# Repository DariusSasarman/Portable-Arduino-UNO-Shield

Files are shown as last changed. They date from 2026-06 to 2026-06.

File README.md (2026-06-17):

# Portable-Arduino-UNO-Shield

## What is it?

A shield that you can use to upgrade older Arduino UNO boards such that your projects don't need extra batteries nor cables. Just the one your phone uses!

## How does it look?



## Physical details:
- **Input:** USB-C (5V, up to 2A for charging)
- **Battery:** 14500 Li-ion Rechargeable (3.7V, 500mAh)
- **Output:** 5V through boost converter ( -0.6V diode voltage drop when running on usb-c !!! )
- **Board Size:** Aprox. 91.5 × 53.4 mm

## Main components
- **Charging IC:** Handles the Li-ion charging (MCP73831-2-OT)
- **Boost Converter:** Steps up 3.7V from the battery to 5V for the Arduino (TPS61200DRC)
- **MOSFET:** Disconects the battery from output when current is fed from USB (PMOS)
- **Reverse Blocking Diode:** Makes sure current doesn't flow backward
- **ESD Diode:** Protects against static discharge on the USB data lines (USBLC6-2SC6)
- **USB to UART converter:** Translates the data lines to actual information (CH340E)

## Installation & usage
1. Pop the 14500 battery into the holder(  Watch the polarity!)
2. Stack the shield onto your Arduino UNO
3. Plug in USB-C to charge (the LED being on means the battery charging)
4. When done charging, unplug and turn on the switch!

## Schematic


## How would this prove useful?

Ever had a project that needed the arduino to be mounted somewhere such that a USB connection couldn't have been possible? I did.

## How did I make it?

I build it by integrating both a standard Li-ion charging circuit (MCP73831 reference design) with a boost converter topology and a USB-serial interface. Added my own custom changes to these, such as the LED and battery switch. It has been a wonderful experiment.

**Key Learnings:** decoupling capacitors, pull-down resistors, step-up boost converters usage, usb-to-uart translation as a requirement.

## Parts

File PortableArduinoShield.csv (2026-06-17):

Reference | Value | Footprint | Datasheet | Qty | DNP
BT1 | 500mAh | Battery:BatteryHolder_Keystone_2460_1xAA |  | 1
C1 | 10n | Capacitor_SMD:C_0603_1608Metric |  | 1
C2 | 100n | Capacitor_SMD:C_0603_1608Metric |  | 1
C3 | 1uF | Capacitor_SMD:C_0603_1608Metric |  | 1
C4,C6,C7 | 4.7uF | Capacitor_SMD:C_0603_1608Metric |  | 3
C5 | 22uF | Capacitor_SMD:C_0603_1608Metric |  | 1
D1 | LED | LED_SMD:LED_0603_1608Metric |  | 1
D2 | D_Schottky | Diode_SMD:D_SOD-123 |  | 1
J1 | Power | Connector_PinSocket_2.54mm:PinSocket_1x08_P2.54mm_Vertical |  | 1
J2,J4 | Digital/PWM | Connector_PinSocket_2.54mm:PinSocket_1x08_P2.54mm_Vertical,Connector_PinSocket_2.54mm:PinSocket_1x10_P2.54mm_Vertical |  | 2
J3 | Analog | Connector_PinSocket_2.54mm:PinSocket_1x06_P2.54mm_Vertical |  | 1
J5 | USB_C_Receptacle_USB2.0_14P | Connector_USB:USB_C_Receptacle_HCTL_HC-TYPE-C-16P-01A | https://www.usb.org/sites/default/files/documents/usb_type-c.zip | 1
L1 | 2.2uH | Inductor_SMD:L_Bourns-SRN4018 |  | 1
Q1 | PMOS | Package_TO_SOT_SMD:SOT-23 | https://ngspice.sourceforge.io/docs/ngspice-html-manual/manual.xhtml#cha_MOSFETs | 1
R1,R2 | 5.1k | Resistor_SMD:R_0603_1608Metric |  | 2
R3 | 2M | Resistor_SMD:R_0603_1608Metric |  | 1
R4 | 180k | Resistor_SMD:R_0603_1608Metric |  | 1
R5 | 2k | Resistor_SMD:R_0603_1608Metric |  | 1
R6 | 470 | Resistor_SMD:R_0603_1608Metric |  | 1
R7 | 10k | Resistor_SMD:R_0603_1608Metric |  | 1
U1 | TPS61200DRC | Package_SON:Texas_S-PVSON-N10_ThermalVias | http://www.ti.com/lit/ds/symlink/tps61200.pdf | 1
U2 | CH340E | Package_SO:MSOP-10_3x3mm_P0.5mm | https://www.mpja.com/download/35227cpdata.pdf | 1
U3 | MCP73831-2-OT | Package_TO_SOT_SMD:SOT-23-5 | http://ww1.microchip.com/downloads/en/DeviceDoc/20001984g.pdf | 1
VCC1 | USBLC6-2SC6 | Package_TO_SOT_SMD:SOT-23-6 | https://www.st.com/resource/en/datasheet/usblc6-2.pdf | 1

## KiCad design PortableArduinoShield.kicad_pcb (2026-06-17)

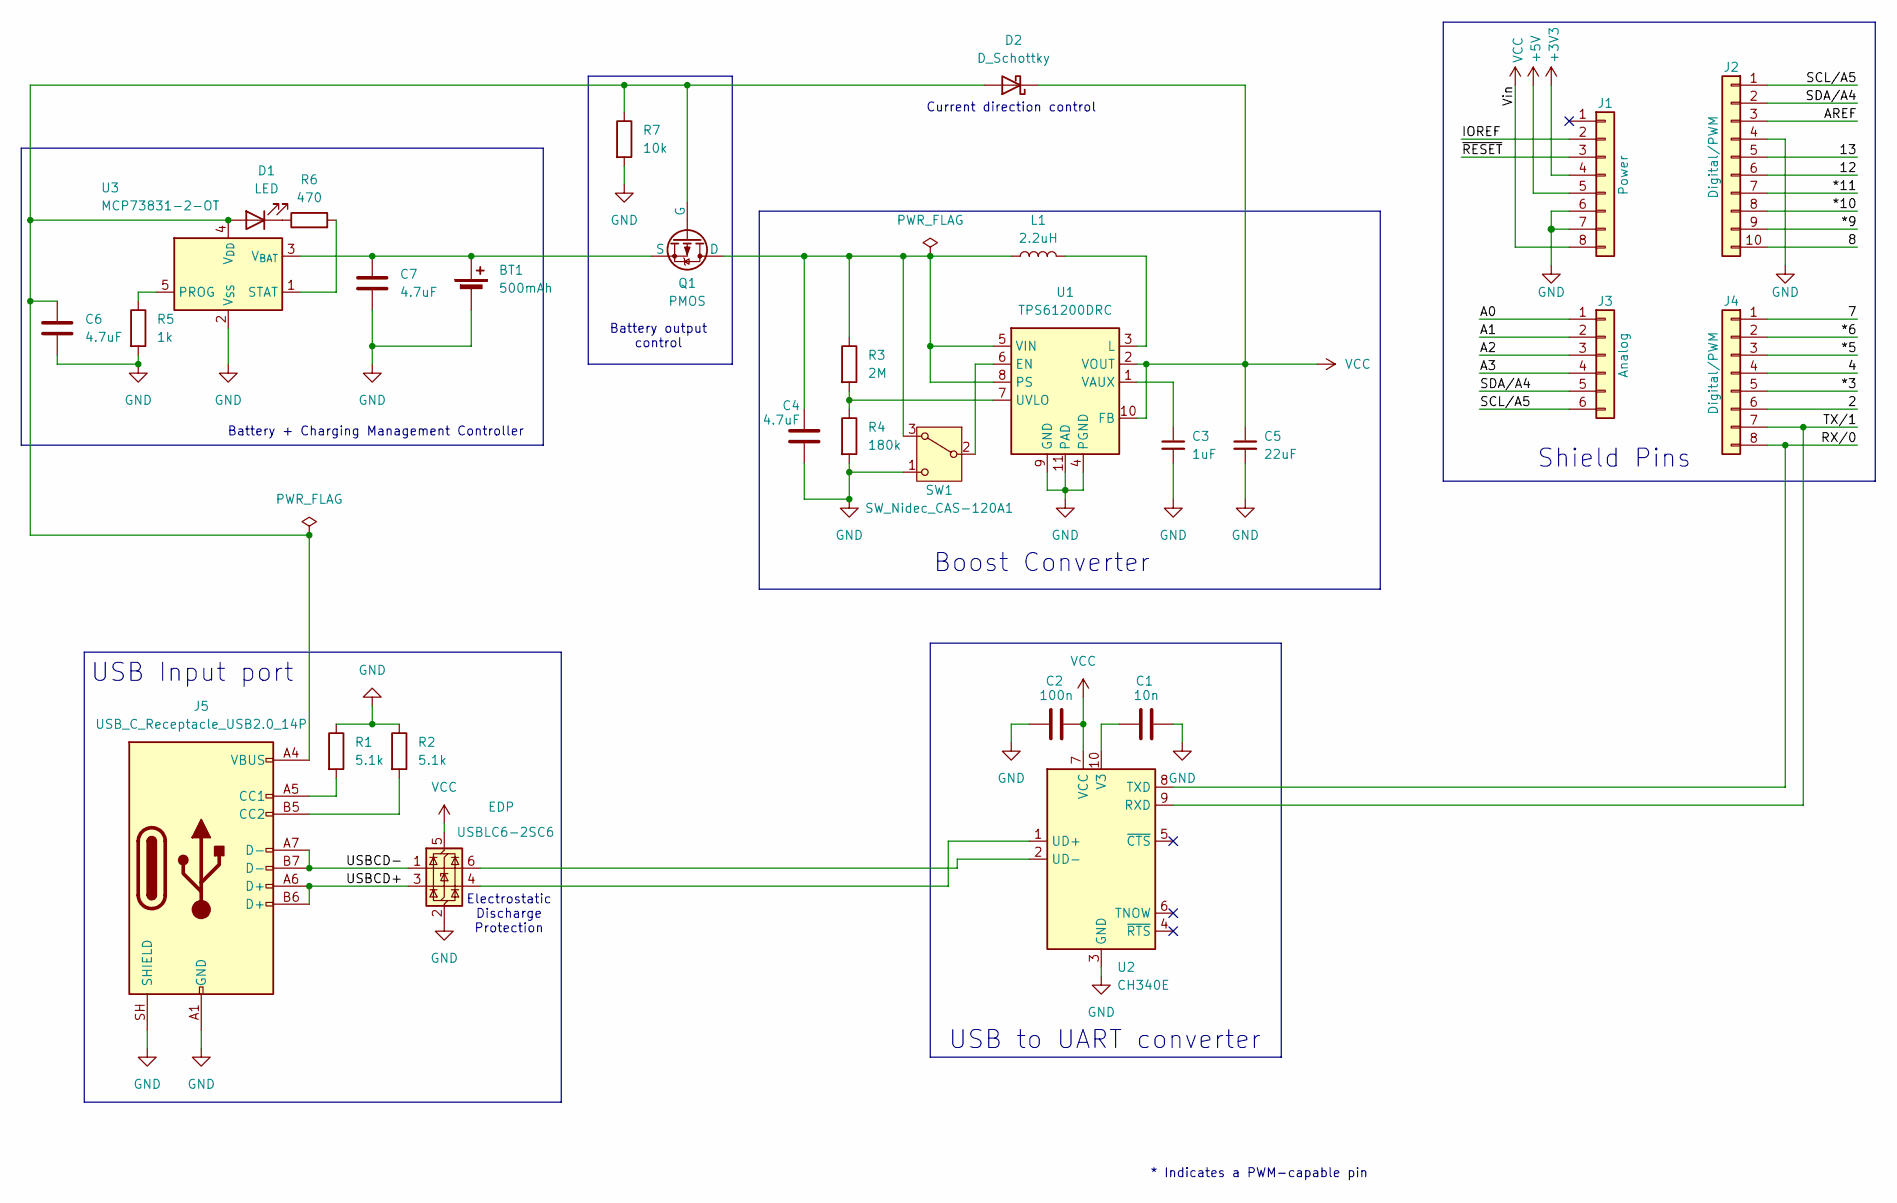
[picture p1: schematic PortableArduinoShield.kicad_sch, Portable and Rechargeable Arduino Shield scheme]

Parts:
BT1: 500mAh; BatteryHolder_Keystone_1042_1x18650
C1: 10n; C_0603_1608Metric
C2: 100n; C_0603_1608Metric
C3: 1uF; C_0603_1608Metric
C4, C6, C7: 4.7uF; C_0603_1608Metric
C5: 22uF; C_0603_1608Metric
D1: LED; LED_0603_1608Metric
D2: D_Schottky; D_SOD-123
EDP: USBLC6-2SC6; SOT-23-6
J1: Power; PinSocket_1x08_P2.54mm_Vertical
J2: Digital/PWM; PinSocket_1x10_P2.54mm_Vertical
J3: Analog; PinSocket_1x06_P2.54mm_Vertical
J4: Digital/PWM; PinSocket_1x08_P2.54mm_Vertical
J5: USB_C_Receptacle_USB2.0_14P; USB_C_Receptacle_Amphenol_12401610E4-2A
L1: 2.2uH; L_Bourns-SRN4018
Q1: PMOS; SOT-23
R1, R2: 5.1k; R_0603_1608Metric
R3: 2M; R_0603_1608Metric
R4: 180k; R_0603_1608Metric
R5: 1k; R_0603_1608Metric
R6: 470; R_0603_1608Metric
R7: 10k; R_0603_1608Metric
SW1: SW_Nidec_CAS-120A1; SW_Slide_SPDT_Straight_CK_OS102011MS2Q
U1: TPS61200DRC; Texas_S-PVSON-N10_ThermalVias
U2: CH340E; MSOP-10_3x3mm_P0.5mm
U3: MCP73831-2-OT; SOT-23-5

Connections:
+3V3: J1.4
+5V: J1.5
/2: J4.6
/4: J4.4
/7: J4.1
/8: J2.10
/12: J2.6
/13: J2.5
/*3: J4.5
/*5: J4.3
/*6: J4.2
/*9: J2.9
/*10: J2.8
/*11: J2.7
/A0: J3.1
/A1: J3.2
/A2: J3.3
/A3: J3.4
/AREF: J2.3
/IOREF: J1.2
/RX/0: J4.8, U2.8 (TXD)
/SCL/A5: J2.1, J3.6
/SDA/A4: J2.2, J3.5
/TX/1: J4.7, U2.9 (RXD)
/USBCD+: EDP.3 (I/O2), J5.A6 (D+), J5.B6 (D+); also elsewhere on the board
/USBCD-: EDP.1 (I/O1), J5.A7 (D-), J5.B7 (D-); also elsewhere on the board
/~RESET: J1.3
GND: BT1.2 (-), C1.1, C2.2, C3.2, C4.2, C5.2, C6.2, C7.2, EDP.2 (GND), J1.6, J1.7, J2.4, J5.A1 (GND), J5.A12 (GND), J5.B1 (GND), J5.B12 (GND), J5.SH (SHIELD), R1.1, R2.1, R4.2, R5.2, R7.2, SW1.1 (C), U1.4 (PGND), U1.9 (GND), U1.11 (PAD), U2.3 (GND), U3.2 (V_{SS}); also elsewhere on the board
unnamed: BT1.1 (+), C7.1, Q1.3 (S), U3.3 (V_{BAT})
unnamed: C6.1, D1.2 (A), D2.2 (A), J5.A4 (VBUS), J5.A9 (VBUS), J5.B4 (VBUS), J5.B9 (VBUS), Q1.2 (G), R7.1, U3.4 (V_{DD})
unnamed: D1.1 (K), R6.1
unnamed: J5.A5 (CC1), R1.2
unnamed: J5.B5 (CC2), R2.2
unnamed: C4.1, L1.1, Q1.1 (D), R3.1, SW1.3 (A), U1.5 (VIN), U1.8 (PS)
unnamed: SW1.2 (B), U1.6 (EN)
unnamed: L1.2, U1.3 (L)
unnamed: R3.2, R4.1, U1.7 (UVLO)
unnamed: C3.1, U1.1 (VAUX)
unnamed 38: EDP.4 (I/O2), U2.1 (UD+); also elsewhere on the board
unnamed 39: EDP.6 (I/O1), U2.2 (UD-); also elsewhere on the board
unnamed: C1.2, U2.10 (V3)
unnamed: R5.1, U3.5 (PROG)
unnamed: R6.2, U3.1 (STAT)
VCC: C2.1, C5.1, D2.1 (K), EDP.5 (VBUS), J1.8, U1.2 (VOUT), U1.10 (FB), U2.7 (VCC); also elsewhere on the board

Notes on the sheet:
USB Input port
Battery output control
USB to UART converter
Shield Pins
Current direction control
Electrostatic Discharge Protection
Battery + Charging Management Controller
* Indicates a PWM-capable pin
Boost Converter

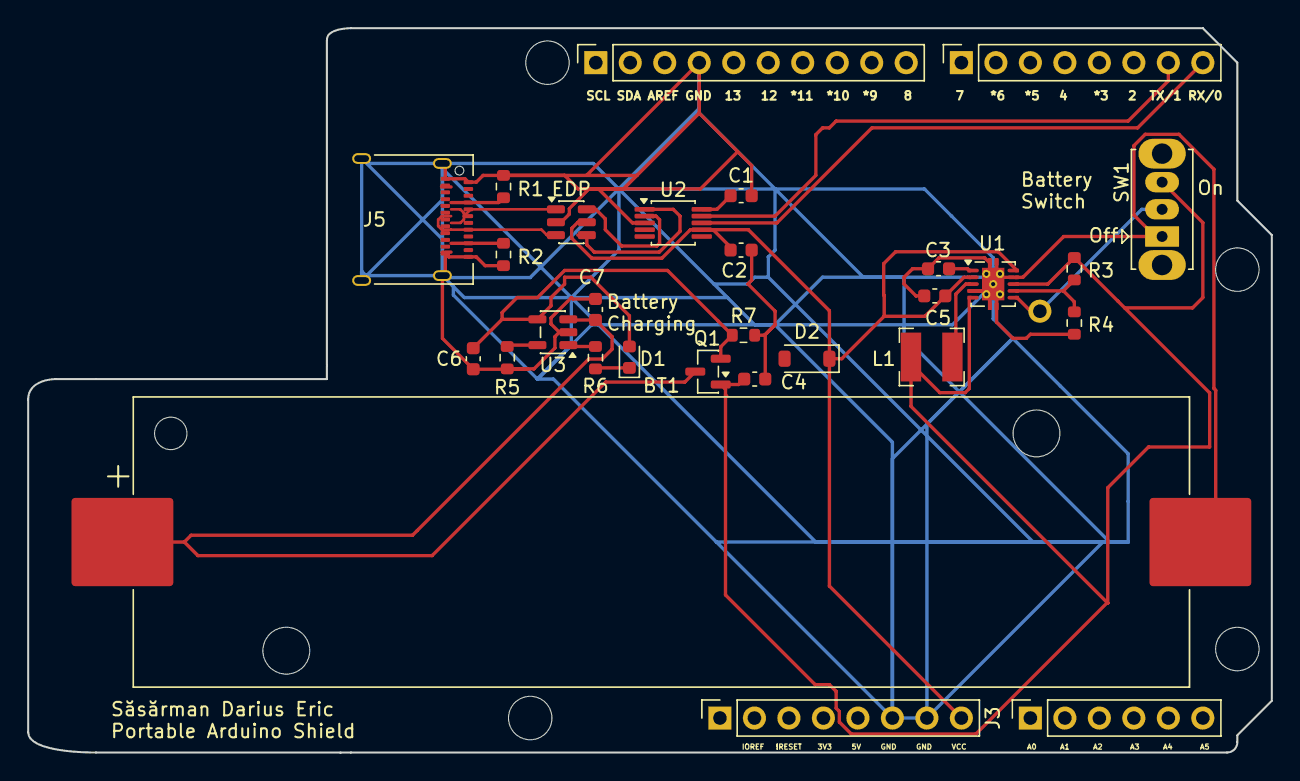
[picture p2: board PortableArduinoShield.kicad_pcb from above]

Board: 2 copper layers, 91.6 x 53.3 mm, 33 parts (0 on the bottom side), 23 nets.

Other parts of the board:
MH1, MH2, MH3, MH4: MountingHole_3.2mm
VCC1: USBLC6-2SC6; SOT-23-6

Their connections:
/USBCD+: VCC1.3 (I/O2); also elsewhere on the board
/USBCD-: VCC1.1 (I/O1); also elsewhere on the board
GND: VCC1.2 (GND); also elsewhere on the board
unnamed 38: VCC1.4 (I/O2); also elsewhere on the board
unnamed 39: VCC1.6 (I/O1); also elsewhere on the board
VCC: VCC1.5 (VBUS); also elsewhere on the board

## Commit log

2026-06-17 Add KiCad badge to README
2026-06-17 Add KiCad file types to .gitattributes
